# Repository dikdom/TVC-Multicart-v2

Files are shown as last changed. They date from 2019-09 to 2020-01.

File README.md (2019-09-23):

# TVC-Multicart-v2
Copyright (C) 2017-2019 by Sandor Vass <vass.sanyi@gmail.com>  
All rights reserved.

# About #
The multicart is a flash storage device for the Videoton TV Computer, 
inserted to the left side expansion slot (program-module).
This repository contains all the related source files to build one 
from scratch.

# Structure #

*  doc

   Contains descriptions and help how to solder and program a module.
   Also a short explanation the structure of the repo, Hungarian.

*  hardware

   Eagle source files and gerber files of the PCB.

*  software

   *  firmware

      The multicart firmware source and binary, that drives the whole stuff. The
      binary is needed to build a complete multicart.

   *  rom-builder

      The source of the Lazarus program (Multiplatform, free pascal IDE), that 
      aids the building of the ROM images to be written to the onboaed EEPROM chips.

   *  tvcpla

      The source of the pla binary generator, and the generated binary also.

# License #

The firmware itself is distributed under the following conditions:

    Redistribution and use in source and binary forms, with or without
    modification, are permitted provided that the following conditions
    are met:
    1. Redistributions of source code must retain the above copyright
       notice, this list of conditions and the following disclaimer.
    2. Redistributions in binary form must reproduce the above copyright
       notice, this list of conditions and the following disclaimer in the
       documentation and/or other materials provided with the distribution.

    THIS SOFTWARE IS PROVIDED BY THE REGENTS AND CONTRIBUTORS ``AS IS'' AND
    ANY EXPRESS OR IMPLIED WARRANTIES, INCLUDING, BUT NOT LIMITED TO, THE
    IMPLIED WARRANTIES OF MERCHANTABILITY AND FITNESS FOR A PARTICULAR PURPOSE
    ARE DISCLAIMED.  IN NO EVENT SHALL THE REGENTS OR CONTRIBUTORS BE LIABLE
    FOR ANY DIRECT, INDIRECT, INCIDENTAL, SPECIAL, EXEMPLARY, OR CONSEQUENTIAL
    DAMAGES (INCLUDING, BUT NOT LIMITED TO, PROCUREMENT OF SUBSTITUTE GOODS
    OR SERVICES; LOSS OF USE, DATA, OR PROFITS; OR BUSINESS INTERRUPTION)
    HOWEVER CAUSED AND ON ANY THEORY OF LIABILITY, WHETHER IN CONTRACT, STRICT
    LIABILITY, OR TORT (INCLUDING NEGLIGENCE OR OTHERWISE) ARISING IN ANY WAY
    OUT OF THE USE OF THIS SOFTWARE, EVEN IF ADVISED OF THE POSSIBILITY OF
    SUCH DAMAGE.

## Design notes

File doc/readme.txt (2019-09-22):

v2.12beta

doc:
  readme.txt: ez a file, amit most olvasol
  BOM : bill of material. Mik kellenek az összeszereléshez (angolul, magyarul)
  FLASH : hogyan s mit kell kiírni, hogy elinduljon a multicart (angolul, magyarul)

hardware:
  eagle:
    Eagle v8.3.1 file -ok a tervezéshez, újratervezéshez.
  gerber6-7.zip
    gerber file -ok a rendeléshez. Az utolsó, mûködõ változat.

software:
  firmware:
    multicart_v2.12.bin
      A multicart firmware bináris, már lefordított állománya. Ezt a programot kell a 0. BANK elejére írni.
      Ezt a binárist használja a RomMaker is. Másold oda az exe mellé!
    *.z80 file-ok
      A multicart firmware forrása. Meg lehet tenni azt is, hogy csak egy cart image kerül az 1. ROM elejére,
      nyilván akkor az fog elindulni és nem lesz több, választható ROM a cart-on.
      Én az ASM80.com nevû online IDE -ben fejlesztettem, ott módosítás nélkül
      fordítható a program (a main file: multicart_v2.1.z80), remélem máshol is
      egyszerûen fordítható.
      A használt nyelv egy kapcsolóval állítható (és belefordul a binárisba, azaz futás
      közben nem lehet változtatni). Ezt a változót kell állítani:
        LANG
      Jelenleg támogatott nyelvek: magyar (HU), angol (EN), spanyol (ES)
  tvcpla:
    tvcpla.pas
      Azon bináris file generáló program forrása, melyet a PLA chip-be (logikai kapuk
      helyett) kell majd égetni.
      Abban az esetben, ha nem 128kB -os a ROM, akkor a legfölsõ 128kB -ba kell írni
      a legenerált binárist
    tvcpla.bin
      A már legenerált bináris file
  rom-builder:
    Lazarus forrás file-ok. A program (+az elkészített firmware bináris + CAS és CART
    binárisok) segítségével lehet olyan bináris ROM file-okat készíteni, amiket az 
    EEPROM-okba írva fog a multicart elindulni és file-ok listáját adni.
    Windows alatt fejlesztettem és futtattam, ott mennie kell.
    Futtatás elott másold be az .exe mellé a fent említett  multicart_v2.12.bin  file-t!

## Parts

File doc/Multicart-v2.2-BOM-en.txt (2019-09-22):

All the components are marked on the PCB, you shall not miss anything. If you have question, ask first, solder later!

4x	100nF, 1# (min 16V, I use X7R or the disc ones. Both are fine and cheap)
1x	22uF, 1# (4mm diameter, 16V, I use submini, 4x7mm)
1x	47uF, 1# (5mm diameter, 16V, I use submini, 5x7mm)
2x	1N4148 diode, 2#
1x	resistor 1k, 3#
1x	resistor 4k7, 3#
1x	resistor 5k1, 3#
1x	resistor 10k, 3#
1x	resistor bridge, 10k, 8+1pin
1x	47pF, 1# (disc form)
1x	68pF, 1# (disc form)
1x	3mm red LED
1x3	pin header + 1x jumper (RAM selector: it is either set to 512kB or less)

(LS or HCT, whichever you can get cheaper)
1x 	74HCT32 	(+ DIP-14 socket)
1x 	74HCT74 	(+ DIP-14 socket)
1x 	74HCT123	(+ DIP-16 socket)
1x 	74HCT273	(+ DIP-20 socket)
1x 	DIP-32 socket
3x 	PLCC-32 through-hole socket (non-SMD!!)

1x	SST39SF010A (128kB flash)
2x	SST39SF040 (512kB flash)

1x	HM628128 (128kB SRAM). Optional, currently no SW uses the onboard RAM...

I believe it is worth seating the chips in sockets, though the logic ones are not necessary to do so.

You can order SRAM from ebay, or new ones (AS6C1008). If you buy from ebay (probably used one - a lot cheaper) then use precision DIP-32 slot instead of the cheap one.

1# means 2.54mm distance (1 raster)
3# means 3x2.54mm distance (3 raster)

Before soldering in the 5k1 resistor, check if the LED is bright enough for you! 5k1 for red LED is OK for me, but you might get different LED supplies...

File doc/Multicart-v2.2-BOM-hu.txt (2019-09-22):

Minden alkatrész szépen jelölve van a nyáklapon. Ha kérdésed van: kérdezz és csak utána forrassz!

4x	100nF, 1# (min 16V,  X7R vagy kőporc. Mindkettő jó)
1x	22uF, 1# (4mm átmérő, 16V, én eddig subminit használtam, 4x7mm)
1x	47uF, 1# (5mm átmérő, 16V, én eddig subminit használtam, 5x7mm)
2x	1N4148 dióda, 2#
1x	ellenállás 1k, 3#
1x	ellenállás 4k7, 3#
1x	ellenállás 5k1, 3#
1x	ellenállás 10k, 3#
1x	ellenállás-híd, 10k, 8+1pin
1x	47pF, 1# (korong, kőporc)
1x	68pF, 1# (korong, kőporc)
1x	3mm piros LED
1x3	pin header + 1x jumper (SRAM kiválasztó: vagy 512kB vagy kevesebb)

(LS vagy HCT, amelyiket olcsóbban be tudod szerezni)
1x 	74HCT32 	(+ DIP-14 foglalat)
1x 	74HCT74 	(+ DIP-14 foglalat)
1x 	74HCT123	(+ DIP-16 foglalat)
1x 	74HCT273	(+ DIP-20 foglalat)
1x 	DIP-32 foglalat
3x 	PLCC-32 through-hole foglalat (nem SMD!!)

1x	SST39SF010A (128kB flash)
2x	SST39SF040 (512kB flash)

1x	HM628128 (128kB SRAM). Opcionális, jelenleg nem használja még semmi a SRAM-ot...

Szerintem érdemes minden IC-t (logikai és SRAM) foglalatba tenni, nem muszáj. A flash (PLCC-32 -eseket muszáj foglalatba tenni)

SRAM-ot lehet ebayről venni vagy újat (AS6C1008). Ha ebay-ről szerzed be, akkor érdemes precíziós foglalatot tenni a SRAM alá.

1# :  2.54mm láb távolság (1 raszter)
3# :  3x2.54mm láb távolság (3 raszter)

Mielőtt beforrasztod az 5.1 kOhmos ellenálást nézd meg, hogy a LED elég erősen világít-e. Nekem jó szokott lenni, de ha neked gyenge a fénye, akkor rakj be kisebb ellenállást!

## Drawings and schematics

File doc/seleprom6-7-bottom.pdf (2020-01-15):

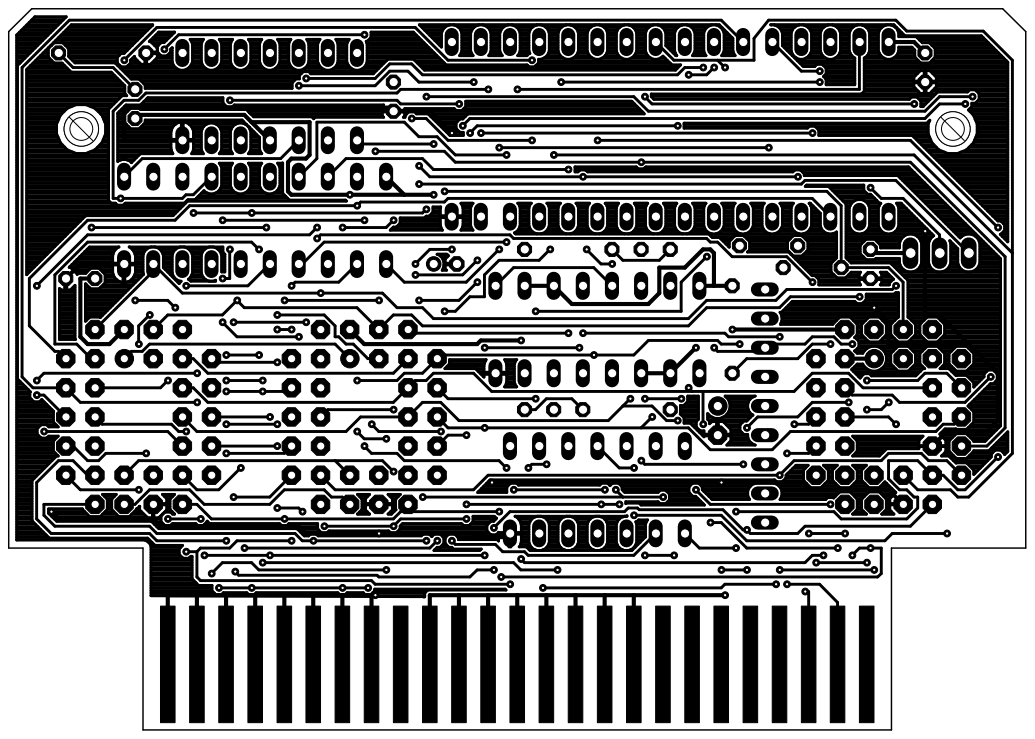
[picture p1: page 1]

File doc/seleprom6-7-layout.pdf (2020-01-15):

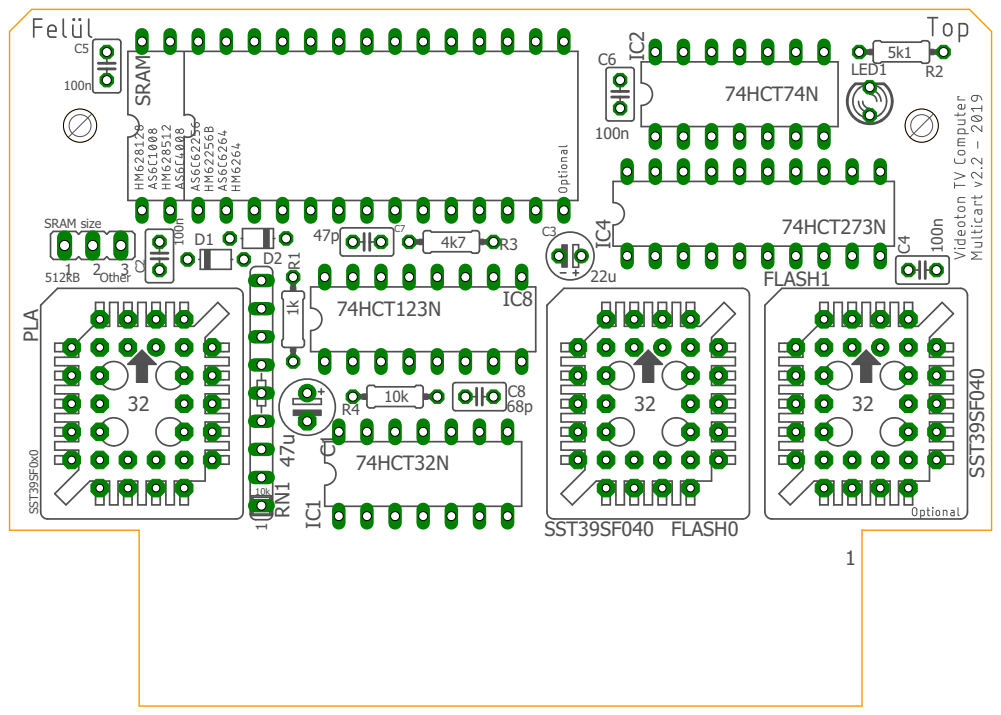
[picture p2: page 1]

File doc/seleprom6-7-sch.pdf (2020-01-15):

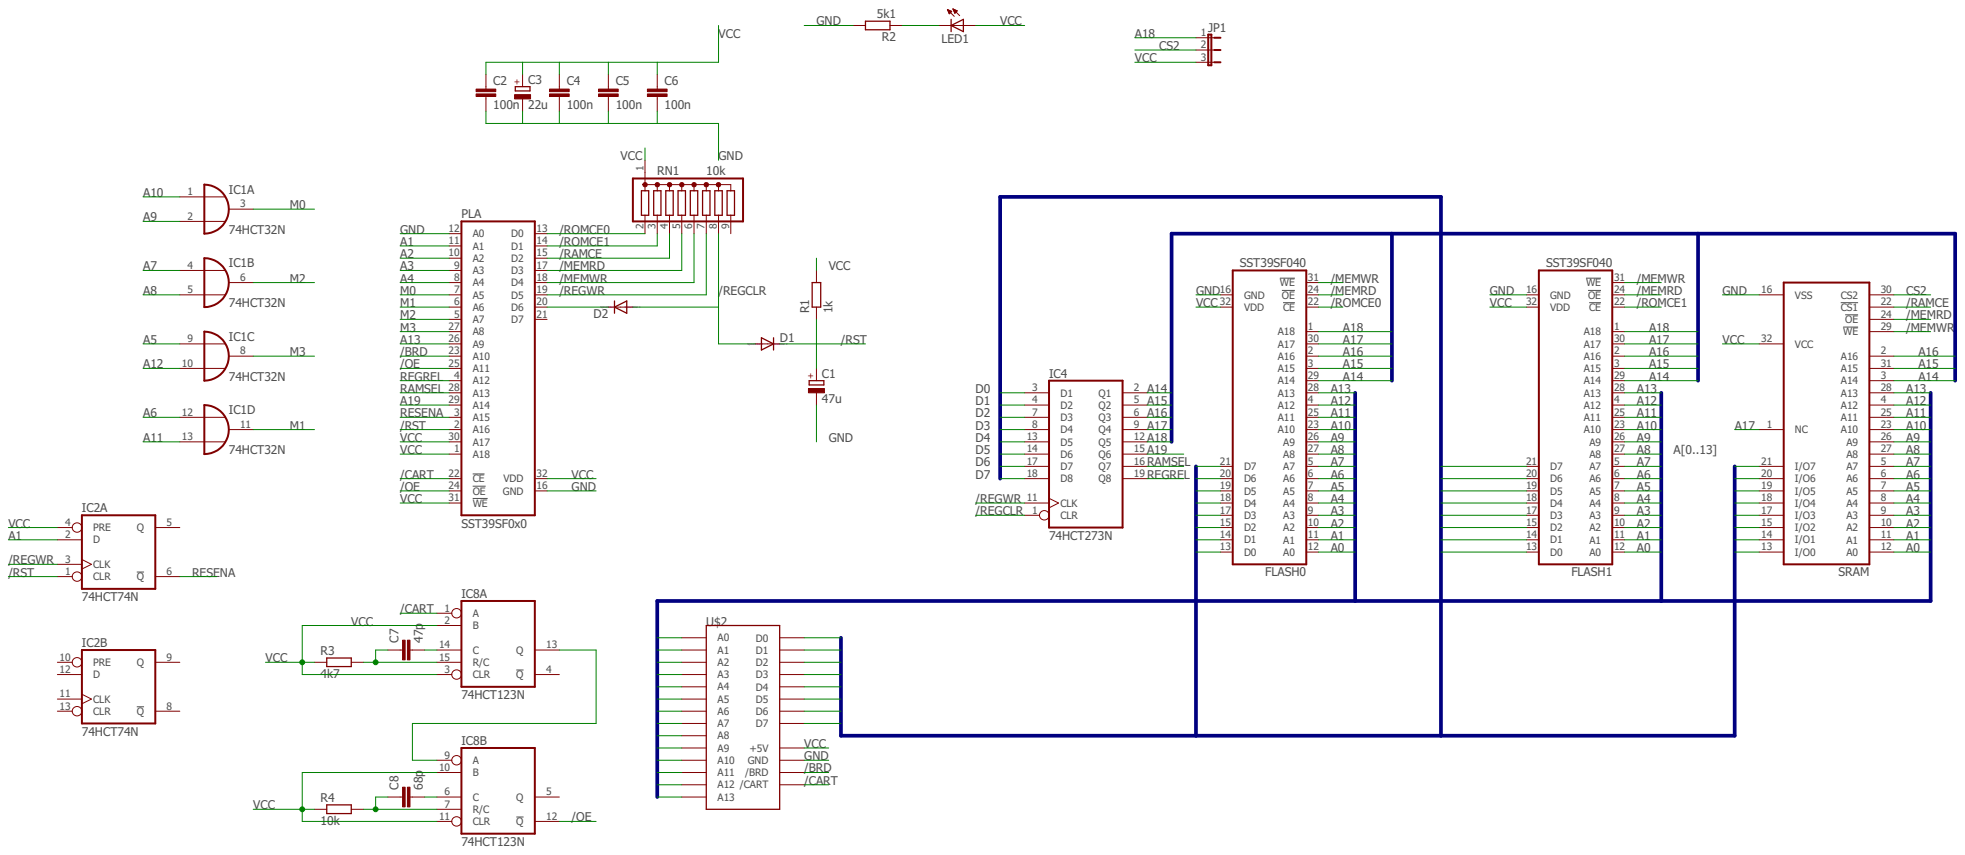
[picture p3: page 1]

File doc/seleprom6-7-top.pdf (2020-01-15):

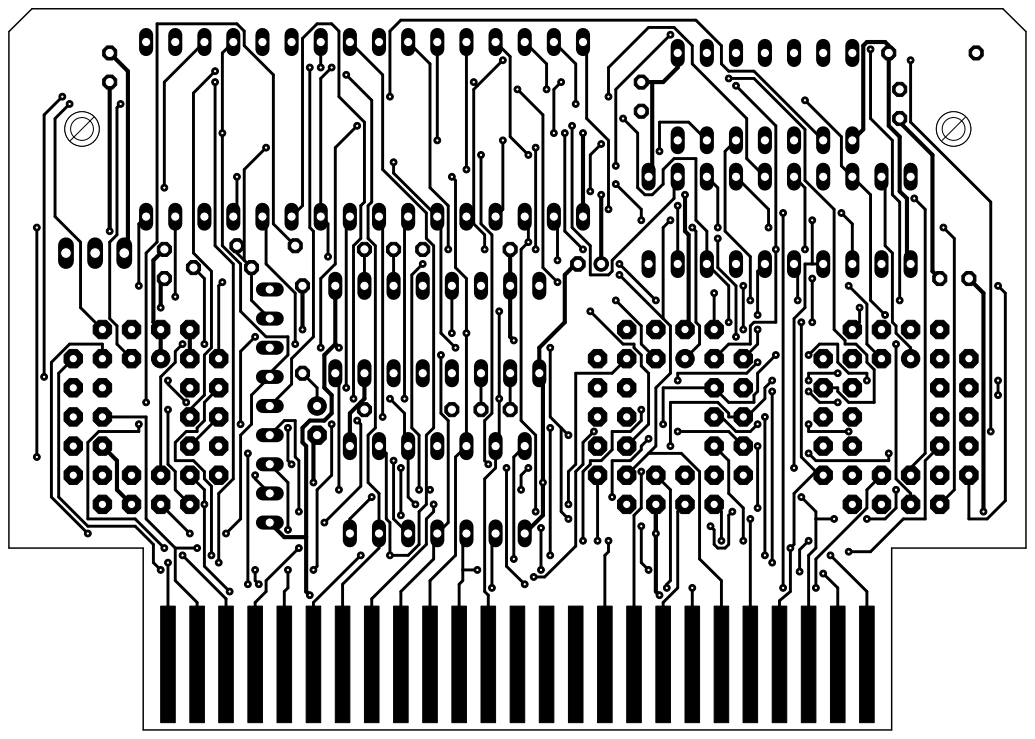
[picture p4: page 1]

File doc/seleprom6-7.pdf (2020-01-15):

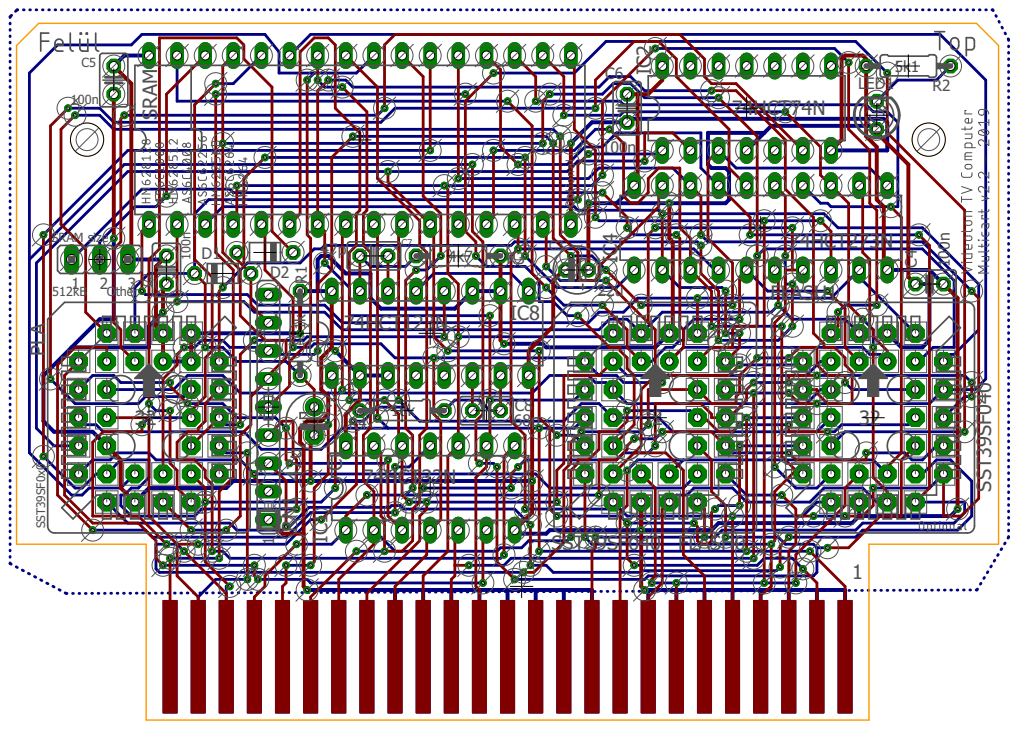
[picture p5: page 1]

74HCT273N

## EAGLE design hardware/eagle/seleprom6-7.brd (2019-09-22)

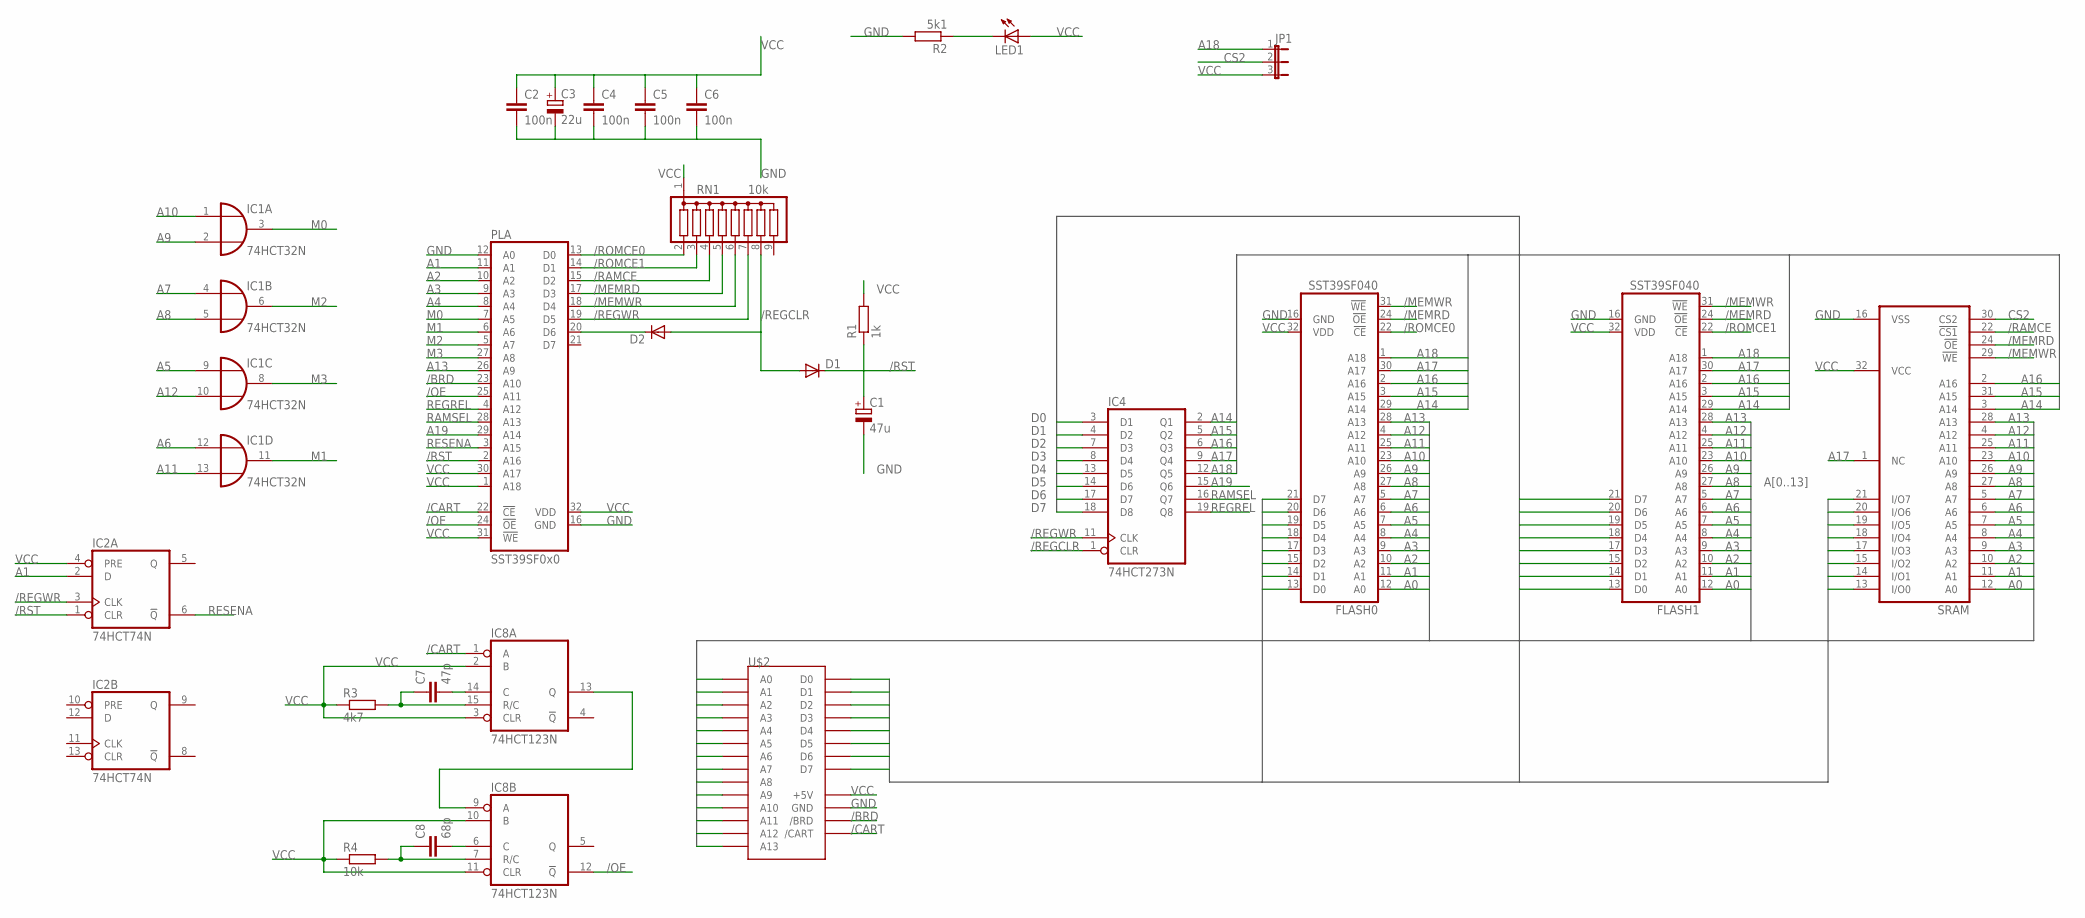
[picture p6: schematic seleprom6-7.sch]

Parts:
C1: 47u; E2,5-5
C2, C4, C5, C6: 100n; C025-025X050
C3: 22u; E2-4
C7: 47p; C025-025X050
C8: 68p; C025-025X050
D1, D2: DIODE-D-5; D-5
FLASH0, FLASH1: SST39SF040; PLCC-SR32
IC1: 74HCT32N; DIL14
IC2: 74HCT74N; DIL14
IC4: 74HCT273N; DIL20
IC8: 74HCT123N; DIL16
JP1: JP2E; JP2
LED1: LED3MM
PLA: SST39SF0x0; PLCC-SR32
R1: 1k; 0204/7
R2: 5k1; 0204/7
R3: 4k7; 0204/7
R4: 10k; 0204/7
RN1: 10k; SIL9
SRAM: 628128P; DIL32
U$2: TVC-CARD+; TVC-CART-CARD

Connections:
/BRD: PLA.23 (A10), U$2.BTM24 (/BRD)
/CART: IC8.1 (A), PLA.22 (!CE), U$2.BTM23 (/CART)
/MEMRD: FLASH0.24 (!OE), FLASH1.24 (!OE), PLA.17 (D3), RN1.5, SRAM.24 (!OE)
/MEMWR: FLASH0.31 (!WE), FLASH1.31 (!WE), PLA.18 (D4), RN1.6, SRAM.29 (!WE)
/OE: IC8.12 (!Q), PLA.24 (!OE), PLA.25 (A11)
/RAMCE: PLA.15 (D2), RN1.4, SRAM.22 (!CS1)
/REGCLR: D1.A, D2.A, IC4.1 (CLR), RN1.8
/REGWR: IC2.3 (CLK), IC4.11 (CLK), PLA.19 (D5), RN1.7
/ROMCE0: FLASH0.22 (!CE), PLA.13 (D0), RN1.2
/ROMCE1: FLASH1.22 (!CE), PLA.14 (D1), RN1.3
/RST: C1.+, D1.C, IC2.1 (CLR), PLA.2 (A16), R1.1
A0: FLASH0.12 (A0), FLASH1.12 (A0), SRAM.12 (A0), U$2.TOP25 (A0)
A1: FLASH0.11 (A1), FLASH1.11 (A1), IC2.2 (D), PLA.11 (A1), SRAM.11 (A1), U$2.TOP2 (A1)
A2: FLASH0.10 (A2), FLASH1.10 (A2), PLA.10 (A2), SRAM.10 (A2), U$2.TOP24 (A2)
A3: FLASH0.9 (A3), FLASH1.9 (A3), PLA.9 (A3), SRAM.9 (A3), U$2.TOP1 (A3)
A4: FLASH0.8 (A4), FLASH1.8 (A4), PLA.8 (A4), SRAM.8 (A4), U$2.TOP21 (A4)
A5: FLASH0.7 (A5), FLASH1.7 (A5), IC1.9 (I0), SRAM.7 (A5), U$2.TOP14 (A5)
A6: FLASH0.6 (A6), FLASH1.6 (A6), IC1.12 (I0), SRAM.6 (A6), U$2.TOP18 (A6)
A7: FLASH0.5 (A7), FLASH1.5 (A7), IC1.4 (I0), SRAM.5 (A7), U$2.TOP17 (A7)
A8: FLASH0.27 (A8), FLASH1.27 (A8), IC1.5 (I1), SRAM.27 (A8), U$2.TOP15 (A8)
A9: FLASH0.26 (A9), FLASH1.26 (A9), IC1.2 (I1), SRAM.26 (A9), U$2.TOP19 (A9)
A10: FLASH0.23 (A10), FLASH1.23 (A10), IC1.1 (I0), SRAM.23 (A10), U$2.TOP22 (A10)
A11: FLASH0.25 (A11), FLASH1.25 (A11), IC1.13 (I1), SRAM.25 (A11), U$2.TOP20 (A11)
A12: FLASH0.4 (A12), FLASH1.4 (A12), IC1.10 (I1), SRAM.4 (A12), U$2.TOP16 (A12)
A13: FLASH0.28 (A13), FLASH1.28 (A13), PLA.26 (A9), SRAM.28 (A13), U$2.TOP23 (A13)
A14: FLASH0.29 (A14), FLASH1.29 (A14), IC4.2 (Q1), SRAM.3 (A14)
A15: FLASH0.3 (A15), FLASH1.3 (A15), IC4.5 (Q2), SRAM.31 (A15)
A16: FLASH0.2 (A16), FLASH1.2 (A16), IC4.6 (Q3), SRAM.2 (A16)
A17: FLASH0.30 (A17), FLASH1.30 (A17), IC4.9 (Q4), SRAM.1 (NC)
A18: FLASH0.1 (A18), FLASH1.1 (A18), IC4.12 (Q5), JP1.1
A19: IC4.15 (Q6), PLA.29 (A14)
CS2: JP1.2, SRAM.30 (CS2)
D0: FLASH0.13 (D0), FLASH1.13 (D0), IC4.3 (D1), SRAM.13 (I/O0), U$2.TOP4 (D0)
D1: FLASH0.14 (D1), FLASH1.14 (D1), IC4.4 (D2), SRAM.14 (I/O1), U$2.TOP5 (D1)
D2: FLASH0.15 (D2), FLASH1.15 (D2), IC4.7 (D3), SRAM.15 (I/O2), U$2.TOP6 (D2)
D3: FLASH0.17 (D3), FLASH1.17 (D3), IC4.8 (D4), SRAM.17 (I/O3), U$2.TOP7 (D3)
D4: FLASH0.18 (D4), FLASH1.18 (D4), IC4.13 (D5), SRAM.18 (I/O4), U$2.TOP8 (D4)
D5: FLASH0.19 (D5), FLASH1.19 (D5), IC4.14 (D6), SRAM.19 (I/O5), U$2.TOP9 (D5)
D6: FLASH0.20 (D6), FLASH1.20 (D6), IC4.17 (D7), SRAM.20 (I/O6), U$2.TOP10 (D6)
D7: FLASH0.21 (D7), FLASH1.21 (D7), IC4.18 (D8), SRAM.21 (I/O7), U$2.TOP3 (D7)
GND: C1.-, C2.2, C3.-, C4.2, C5.2, C6.2, FLASH0.16 (GND), FLASH1.16 (GND), IC1.7 (GND), IC2.7 (GND), IC4.10 (GND), IC8.8 (GND), PLA.12 (A0), PLA.16 (GND), R2.2, SRAM.16 (VSS), U$2.BTM1 (GND), U$2.BTM2 (GND), U$2.BTM3 (GND), U$2.BTM4 (GND), U$2.BTM5 (GND), U$2.BTM6 (GND), U$2.BTM7 (GND), U$2.BTM8 (GND)
M0: IC1.3 (O), PLA.7 (A5)
M1: IC1.11 (O), PLA.6 (A6)
M2: IC1.6 (O), PLA.5 (A7)
M3: IC1.8 (O), PLA.27 (A8)
unnamed: D2.C, PLA.20 (D6)
unnamed: LED1.K (C), R2.1
unnamed: IC8.9 (A), IC8.13 (Q)
unnamed: C7.2, IC8.14 (C)
unnamed: C8.2, IC8.6 (C)
unnamed: C8.1, IC8.7 (R/C), R4.2
unnamed: C7.1, IC8.15 (R/C), R3.2
RAMSEL: IC4.16 (Q7), PLA.28 (A13)
REGREL: IC4.19 (Q8), PLA.4 (A12)
RESENA: IC2.6 (!Q), PLA.3 (A15)
VCC: C2.1, C3.+, C4.1, C5.1, C6.1, FLASH0.32 (VDD), FLASH1.32 (VDD), IC1.14 (VCC), IC2.4 (PRE), IC2.14 (VCC), IC4.20 (VCC), IC8.2 (B), IC8.3 (CLR), IC8.10 (B), IC8.11 (CLR), IC8.16 (VCC), JP1.3, LED1.A, PLA.1 (A18), PLA.30 (A17), PLA.31 (!WE), PLA.32 (VDD), R1.2, R3.1, R4.1, RN1.1, SRAM.32 (VCC), U$2.BTM10 (+5V), U$2.BTM11 (+5V), U$2.BTM12 (+5V), U$2.BTM13 (+5V), U$2.BTM14 (+5V), U$2.BTM15 (+5V), U$2.BTM16 (+5V), U$2.BTM17 (+5V)

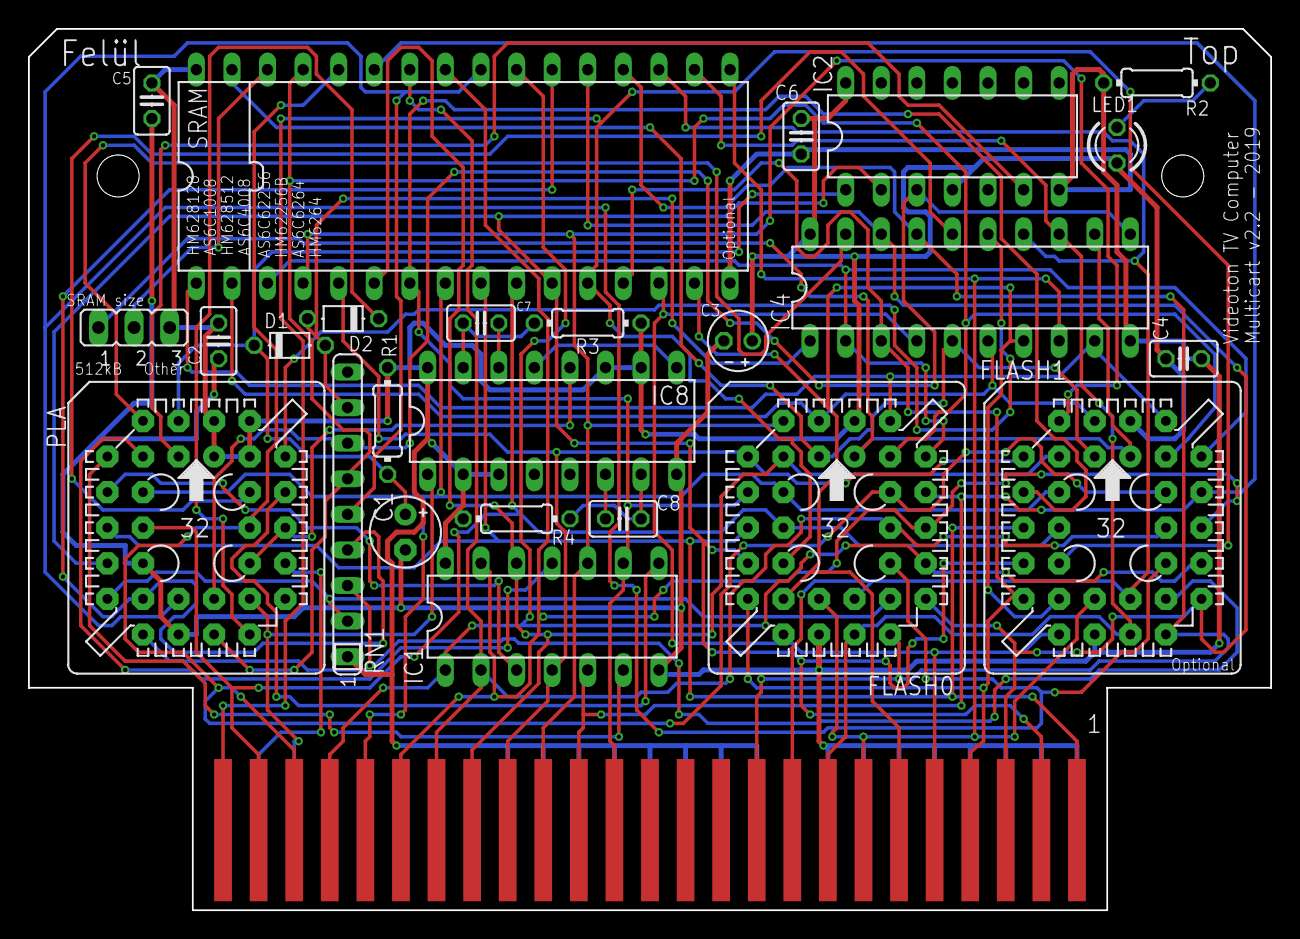
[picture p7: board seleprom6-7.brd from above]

Board: 2 copper layers, 88.7 x 62.9 mm, 26 parts (0 on the bottom side), 56 nets.

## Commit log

2019-09-22 Initial commit message. This commit contains all the files needed for building a TVC Multicart card from scratch.
    [seleprom6-7.brd, seleprom6-7.sch]
2020-01-15 pdf files added
    Schematics, layout and print files (for DIY warriors) in PDF format.
